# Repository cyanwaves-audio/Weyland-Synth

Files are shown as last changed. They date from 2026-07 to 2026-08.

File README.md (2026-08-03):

# Weyland DOS-1

<p align="center">
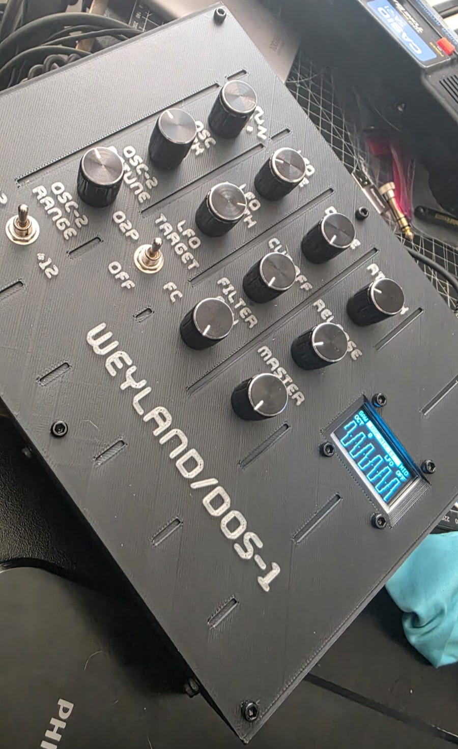
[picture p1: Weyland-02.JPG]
Weyland DOS-1 synthesizer
  
</p>

Weyland DOS-1 is a digital monophonic synthesizer built from scratch around an ESP32-S3.

It features two oscillators, waveform selection, oscillator mix and detune, an AR envelope, a low-pass filter, drive, and an LFO assignable to oscillator 2 pitch or filter cutoff (or off). Audio is generated at 48 kHz and sent through a PCM5102A DAC.

Weyland accepts USB MIDI directly as a device or through an RP2040-based USB host bridge, allowing it to work with class-compliant USB MIDI controllers without a computer.

[Watch it in action here.](https://youtu.be/kIQRiqMi21E)
## Overview

The project includes the synthesizer firmware, USB MIDI host firmware, wiring documentation, component list, and files for the custom 3D-printed enclosure.

Weyland DOS-1 was designed as a complete playable instrument rather than a development board experiment: all user-adjustable synthesis parameters have dedicated physical controls, while the OLED displays the current MIDI source, waveform, oscillator range, LFO assignment, parameter values, and a live scope of the final audio output.

## Features

- Digital monophonic synthesizer running at 48 kHz
- Dual oscillators with shared waveform selection
- Oscillator mix, detune, and octave-range controls
- Low-pass filter with envelope modulation
- Attack–release amplitude envelope
- LFO with adjustable rate and depth
- LFO routing to oscillator 2 pitch, filter cutoff, or off
- Adjustable drive and master output
- Velocity-sensitive MIDI response
- Last-note priority with held-note fallback
- Direct USB MIDI device mode
- USB MIDI host mode through an RP2040 bridge
- OLED status display with live parameter feedback and output waveform scope
- Dedicated physical controls for every synthesis parameter
- PCM5102A I²S audio output
- Custom 3D-printed enclosure

## Architecture

Weyland is built around an ESP32-S3, which runs the synthesis engine, processes the physical controls, receives MIDI, updates the OLED, and sends digital audio to the DAC.

| Component | Function |
| --- | --- |
| ESP32-S3 | Synthesis engine, control processing, MIDI and display |
| RP2040 Pico | USB MIDI host and UART bridge |
| MCP3208 | Eight-channel ADC for the analog controls |
| PCM5102A | 48 kHz I²S digital-to-analog conversion |
| SH1106 OLED | MIDI mode, octave and LFO status display |

MIDI can reach the synthesizer through two paths:

- **Device mode:** A computer or USB host connects directly to the ESP32-S3.
- **Host mode:** A class-compliant USB MIDI controller connects to the RP2040, which forwards the MIDI data to the ESP32-S3 over UART.

## Controls

| Control | Function |
| --- | --- |
| WAVE | Selects the waveform used by both oscillators |
| OSC MIX | Blends oscillator 1 and oscillator 2 |
| OSC-2 DETUNE | Fine-tunes oscillator 2 relative to oscillator 1 |
| OSC -2 RANGE | Shifts oscillator 2 by −12, 0 or +12 semitones |
| LFO RATE | Sets the modulation speed |
| LFO DEPTH | Sets the modulation amount |
| LFO TARGET | Routes the LFO to the filter, oscillator 2 or off |
| DRIVE | Adds saturation to the signal |
| CUTOFF | Sets the low-pass filter cutoff |
| FILTER ENV | Sets the envelope modulation applied to the filter |
| ATTACK | Sets the amplitude-envelope attack time |
| RELEASE | Sets the amplitude-envelope release time |
| MASTER | Sets the output level |

Weyland is monophonic and uses last-note priority. When the current note is released, it returns to the newest note still being held.

## MIDI

Weyland DOS-1 can receive MIDI in two ways:

* **USB device mode:** connect Weyland directly to a computer or DAW.
* **USB host mode:** connect a class-compliant USB MIDI controller through the internal RP2040 Pico bridge.

In host mode, the Pico reads the USB MIDI data and forwards supported messages to the ESP32-S3 using the custom MGP UART protocol. The selected MIDI source is handled exclusively rather than combining both inputs. The display identifies the active source.

### Supported MIDI messages

| MIDI message | Behaviour |
| --- | --- |
| Note On | Plays the received note. Note velocity controls its level. |
| Note Off | Releases the note, subject to sustain-pedal state. |
| Note On with velocity 0 | Treated as Note Off. |
| Pitch Bend | Bends the pitch of the active voice. |
| CC 1 — Modulation Wheel | Adds MIDI-controlled modulation. |
| CC 64 — Sustain Pedal | Defers note releases while the pedal is held. |
| CC 120 — All Sound Off  | Immediately silences the synth. |
| CC 123 — All Notes Off  | Clears the held-note state and releases the voice. |

Weyland listens on all 16 MIDI channels and uses **monophonic last-note priority**. The newest held note becomes active; releasing it returns to the most recently held previous note. The held-note stack also works with sustain-pedal input. The original note-priority and MGP transport behaviour was established in the earlier bridge firmware and retained in the final version.

Channel pressure, polyphonic aftertouch, program changes, MIDI clock, SysEx, and arbitrary MIDI CC control of the front-panel parameters are not currently implemented.

## Hardware

### Core components

| Component | Purpose |
| --- | --- |
| ESP32-S3-WROOM-1 | Main processor and synthesis engine |
| Raspberry Pi Pico / RP2040 | USB MIDI host bridge |
| PCM5102A module | I²S audio output |
| MCP3208 | 12-bit ADC for eight analog controls |
| 1.3-inch SH1106 OLED | Status display |
| Potentiometers and switches | Synth parameter controls |
| Audio output jack | Line-level audio output |
| USB connectors | Power, direct MIDI and USB-host MIDI |
| Custom 3D-printed enclosure | Panel and electronics housing |

## Wiring and Pin Mapping

### ESP32-S3 connections

| GPIO | Connection |
| ---: | --- |
| 1 | MIDI host/device mode selector |
| 4 | Oscillator mix |
| 5 | Oscillator 2 detune |
| 6, 7 | Oscillator 2 octave selector |
| 9, 10 | LFO target selector |
| 11–14 | Waveform selector |
| 15 | UART MIDI input from the RP2040 bridge |
| 16 | OLED SDA |
| 17 | OLED SCL |
| 35 | PCM5102A LRCK |
| 36 | PCM5102A DIN |
| 37 | PCM5102A BCK |
| 39 | MCP3208 CS |
| 40 | MCP3208 MOSI |
| 41 | MCP3208 MISO |
| 42 | MCP3208 SCK |

### MCP3208 channels

| Channel | Control |
| ---: | --- |
| CH0 | LFO rate |
| CH1 | LFO depth |
| CH2 | Drive |
| CH3 | Filter cutoff |
| CH4 | Filter envelope amount |
| CH5 | Attack |
| CH6 | Release |
| CH7 | Master output |

The supplied firmware compensates for the potentiometer orientation used in the original build. If the controls operate backwards in another build, swap the outer potentiometer connections or change the inversion behavior in the firmware.

## Firmware Setup

Weyland uses two separate firmware sketches:

* The **ESP32-S3 firmware** runs the synthesizer, display, controls, direct USB MIDI and MGP receiver.
* The **RP2040 firmware** acts as a USB MIDI host and forwards MIDI to the ESP32-S3.

### Requirements

* Arduino IDE
* **esp32** board package by Espressif Systems
* **Raspberry Pi Pico/RP2040** board package by Earle F. Philhower III
* Adafruit GFX Library
* Adafruit SH110X Library

TinyUSB host support is included with the RP2040 board package.

### ESP32-S3 firmware

The main synthesizer firmware consists of three files:

* `Weyland_v0_28e.ino`
* `WeylandDisplay.cpp`
* `WeylandDisplay.h`

Keep all three files inside the same Arduino sketch folder.

Use these Arduino IDE settings:

| Setting | Value |
| --- | --- |
| Board | ESP32S3 Dev Module |
| USB CDC On Boot | Disabled |
| USB Mode | USB-OTG (TinyUSB)  |

Compile and upload the sketch to the ESP32-S3.

In DEVICE mode, the ESP32-S3 appears as a USB MIDI device named **Weyland DOS-1**.

The OLED uses I²C address `0x3C`. If the display is missing or fails to initialize, the synthesizer will continue operating without it.

### RP2040 USB host firmware

The USB MIDI host bridge uses:

* `Weyland_Pico_USBHost_HardwareReset_v0_5.ino`

Place this file in its own Arduino sketch folder.

Use these Arduino IDE settings:

| Setting | Value |
| --- | --- |
| Board | Raspberry Pi Pico, or the matching RP2040 board |
| USB Stack | Adafruit TinyUSB Host (native) |

Before uploading, place Weyland’s MIDI source switch in **HOST** mode. In DEVICE mode, the hardware reset circuit holds the Pico in reset.

Because the Pico’s USB port runs as a host instead of a serial device, reflashing may require manually entering BOOTSEL mode:

1. Disconnect the Pico from USB.
2. Hold the **BOOTSEL** button.
3. Reconnect USB and release BOOTSEL.
4. Upload the sketch from Arduino IDE.

### ESP32-S3 and Pico connection

The Pico communicates with the ESP32-S3 using the MGP(1) protocol over UART:

| Pico | ESP32-S3 |
| --- | --- |
| GP0 / UART TX | GPIO15 / UART RX through a 1 kΩ resistor |
| GND | GND |

The UART connection runs at `115200` baud.

In HOST mode, the Pico receives MIDI from a class-compliant USB MIDI controller and forwards note, sustain, modulation and pitch-bend messages to the ESP32-S3. In DEVICE mode, the Pico is held in reset and the ESP32-S3 accepts MIDI through its own USB connection.

The Pico firmware uses GP25 for its status LED. Boards with a NeoPixel or a differently wired LED will still operate as MIDI bridges, but their status indicator may not work without changing `LED_PIN`.

(1) MGP: Midi Gremlin Protocol. Weyland’s lightweight custom serial protocol. It packages USB MIDI events into fixed UART messages sent from the RP2040 host bridge to the ESP32-S3.

## MIDI Source Selection

Weyland supports two mutually exclusive MIDI input paths, selected with the physical HOST/DEVICE switch.

| Mode | MIDI source | Behavior |
| --- | --- | --- |
| DEVICE | ESP32-S3 USB port | Weyland appears as a USB MIDI device named **Weyland DOS-1** |
| HOST | RP2040 USB port | A class-compliant USB MIDI controller connects directly to Weyland |

In HOST mode, the RP2040 converts incoming USB MIDI events into MGP messages and forwards them to the ESP32-S3 over UART.

In DEVICE mode, the RP2040 is held in reset by the hardware reset circuit, preventing both MIDI paths from operating simultaneously.

## Enclosure and 3D-Printing Files

The repository includes the files for Weyland’s custom 3D-printed enclosure.

I designed the enclosure in Autodesk Fusion around the specific boards, modules, controls and connectors used in the original build. Components with different dimensions may require modifications to the model.

Before final assembly, test-fit the OLED, potentiometers, switches, USB connectors and audio jack.

### BOM

Exact MCUs I used:

ESP32-S3 N16R8: https://aliexpress.com/item/1005007319706057.html

Raspberry Pi Pico 16MB: https://aliexpress.com/item/1005005617180169.html

I might update the full BOM sometime, but for now this and the provided schematics should be enough to start.

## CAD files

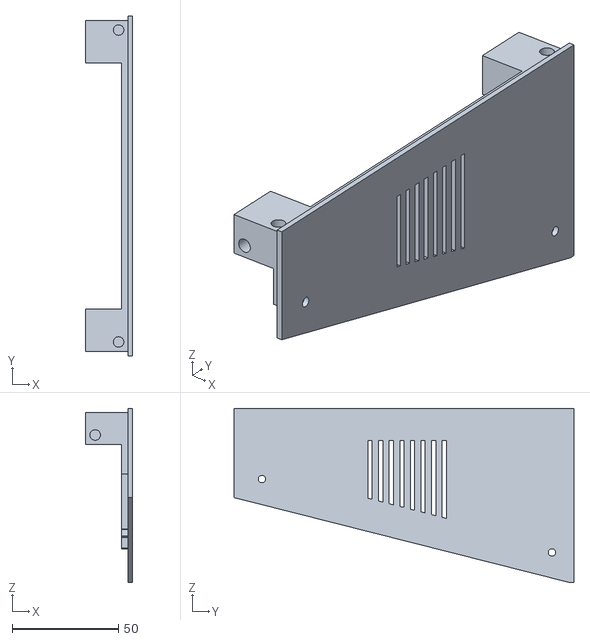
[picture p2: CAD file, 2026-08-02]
3DModels/Weyland_v6_Right.stl
22.0 x 160.0 x 82.0

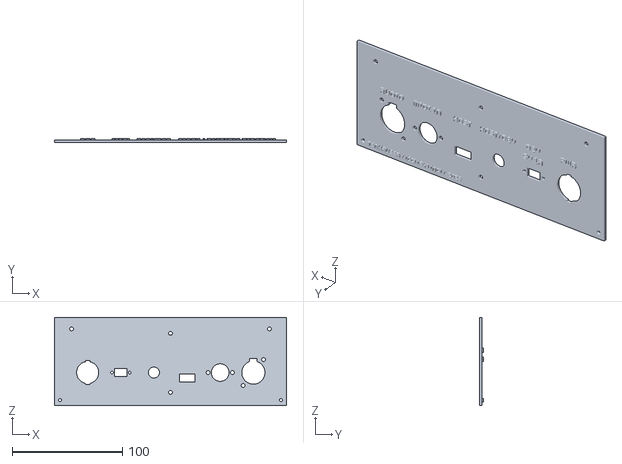
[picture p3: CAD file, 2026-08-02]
3DModels/Weyland_v6_Back.stl
210.0 x 3.50 x 80.0

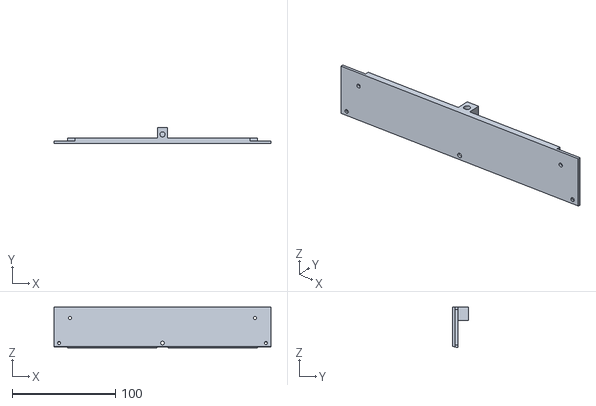
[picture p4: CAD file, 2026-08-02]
3DModels/Weyland_v6_Front.stl
210.0 x 15.0 x 39.3

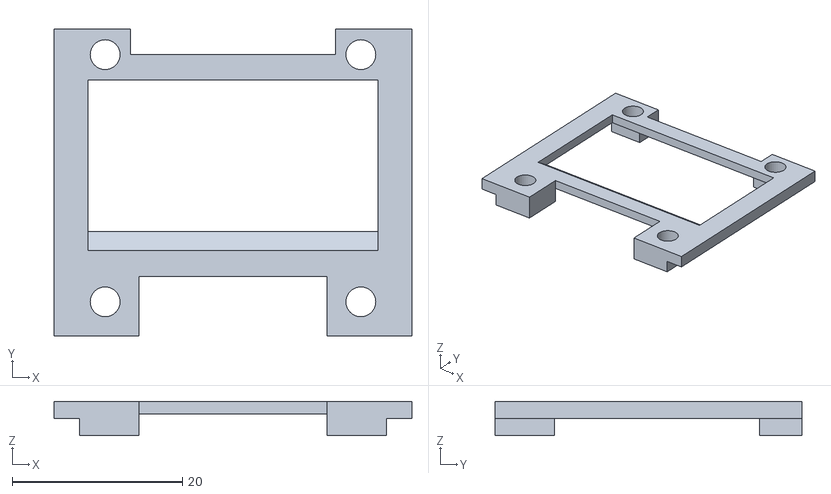
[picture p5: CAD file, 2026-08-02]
3DModels/Weyland_v6_DisplayHolder_rev1.stl
42.0 x 36.0 x 4.00

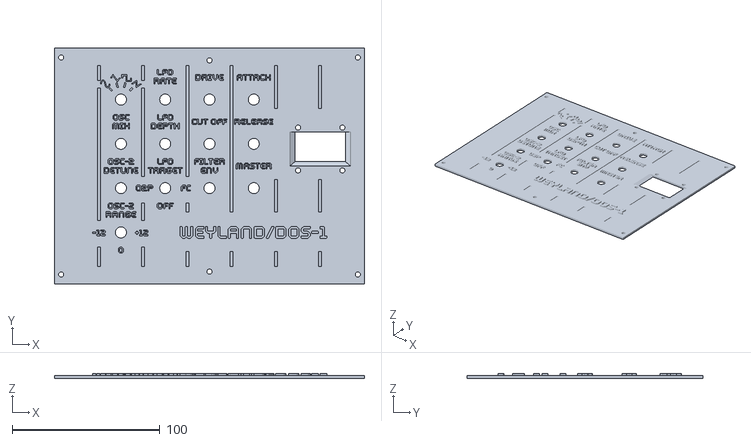
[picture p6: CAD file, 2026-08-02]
3DModels/Weyland_v6_TopPanel_rev1.stl
210.0 x 160.0 x 3.50

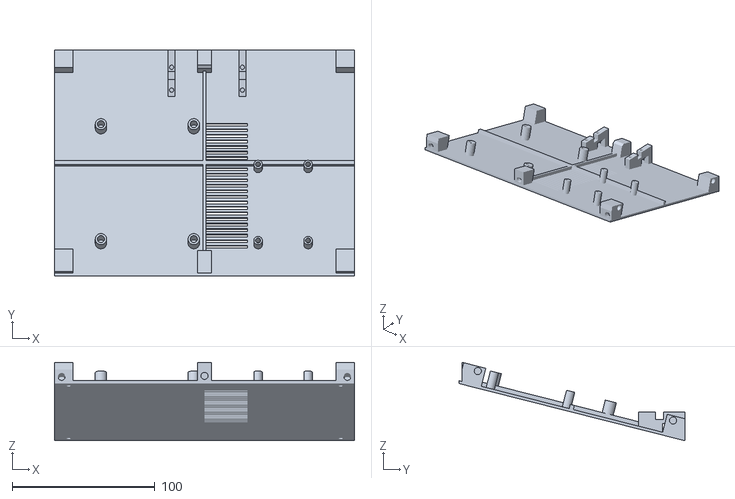
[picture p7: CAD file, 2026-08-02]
3DModels/Weyland_v6_Bottom.stl
210.0 x 158.0 x 54.9

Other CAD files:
3DModels/Weyland_v6_Left.stl

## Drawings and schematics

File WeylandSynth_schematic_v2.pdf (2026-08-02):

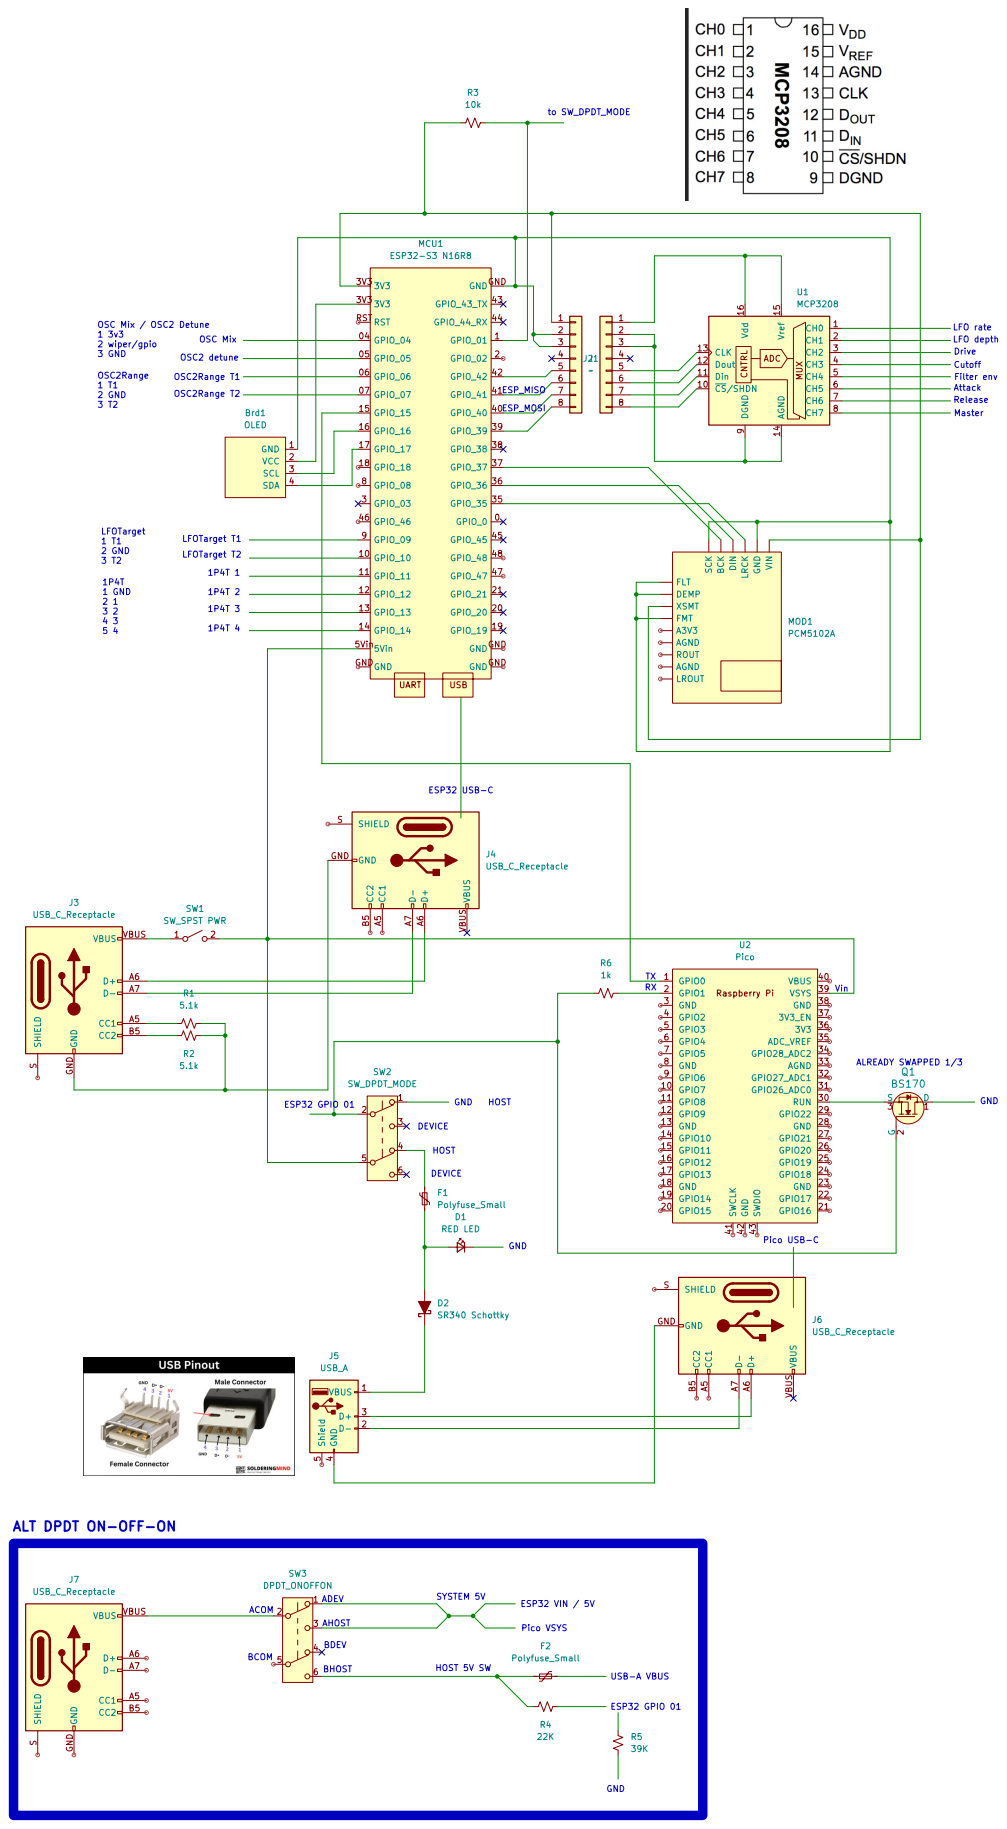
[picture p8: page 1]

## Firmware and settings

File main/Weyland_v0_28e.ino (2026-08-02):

// ============================================================
// Weyland_v0_28e_fixedTimebaseScope
// ESP32-S3 + PCM5102A + MCP3208
//
// Based on Weyland_v0_26_mgpPerformanceControls.
//
// Changes from v0_26:
// - Keeps raw-polled UART1 RX GPIO15; no UART driver / ISR / ringbuffer.
// - Keeps MGP Control Change (0x03) and Pitch Bend (0x04) packets.
// - Makes the physical HOST / DEVICE switch choose exactly one MIDI source.
// - HOST: Pico MGP bridge is accepted; ESP USB MIDI packets are discarded.
// - DEVICE: ESP USB MIDI is accepted; Pico MGP packets are parsed then ignored.
// - Uses GPIO1 INPUT_PULLUP: LOW = HOST, HIGH/open = DEVICE.
// - Debounces mode changes and silences/reset-controls when switching source.
//
// USB CDC On Boot must be Disabled.
// USB Mode: USB-OTG / TinyUSB.
//
// All pots inverted globally because I wired them reversed. Eh.
// Osc2 detune is flipped again because panel direction felt inverted.
// Switches not inverted.
// ============================================================

#include <Arduino.h>
#include <SPI.h>
#include "driver/i2s_std.h"
#include "driver/uart.h"
#include "esp_system.h"
#include "soc/soc.h"
#include "soc/uart_reg.h"
#include <math.h>

#include "USB.h"
#include "USBMIDI.h"
#include "WeylandDisplay.h"

USBMIDI MIDI("Weyland DOS-1");

// -------------------- Types --------------------

enum Waveform {
  WAVE_SINE,
  WAVE_SQUARE,
  WAVE_SAW,
  WAVE_TRIANGLE
};

enum LfoTarget {
  LFO_TARGET_OSC2,
  LFO_TARGET_OFF,
  LFO_TARGET_FILTER
};

// -------------------- Audio --------------------

const int SAMPLE_RATE = 48000;
const int AUDIO_FRAMES = 64;

const int16_t OUTPUT_AMPLITUDE = 24000;
const float SYNTH_HEADROOM_GAIN = 0.55f;

// PCM5102A
const int I2S_WS_PIN   = 35;
const int I2S_DOUT_PIN = 36;
const int I2S_BCK_PIN  = 37;

// -------------------- Direct controls --------------------

const int POT_OSC_MIX_PIN = 4;
const int POT_OSC2_DETUNE_PIN = 5;

const int OSC2_RANGE_LEFT_PIN  = 6;
const int OSC2_RANGE_RIGHT_PIN = 7;

const int LFO_TARGET_LEFT_PIN  = 9;
const int LFO_TARGET_RIGHT_PIN = 10;

const int WAVE_SINE_PIN     = 11;
const int WAVE_TRIANGLE_PIN = 12;
const int WAVE_SQUARE_PIN   = 13;
const int WAVE_SAW_PIN      = 14;

// -------------------- MIDI input source switch --------------------
//
// Wiring on the spare pole of the HOST / DEVICE DPDT switch:
//   Common -> ESP32 GPIO1
//   HOST throw -> GND
//   DEVICE throw -> leave open
//
// INPUT_PULLUP makes an open contact read HIGH.
// Therefore:
//   GPIO1 LOW  = accept Pico USB-host MGP bridge
//   GPIO1 HIGH = accept ESP USB MIDI from the panel USB-C / DAW
const int MIDI_SOURCE_MODE_PIN = 1;
const unsigned long MIDI_SOURCE_DEBOUNCE_MS = 25;

// -------------------- Pico / MGP raw UART bridge --------------------

#define MGP_UART_NUM   UART_NUM_1
#define MGP_RX_PIN     15
#define MGP_BAUD       115200

#define MGP_SYNC_A       0xA5
#define MGP_SYNC_B       0x5A
#define MGP_VER          0x01
#define MGP_MAX_PAYLOAD  16

#define MGP_NOTE_ON         0x01
#define MGP_NOTE_OFF        0x02
#define MGP_CONTROL_CHANGE  0x03
#define MGP_PITCH_BEND      0x04
#define MGP_ALL_NOTES_OFF   0x10
#define MGP_ALL_SOUND_OFF   0x11
#define MGP_ALL_CHANNELS    0xFF

const bool MGP_DEBUG_PRINT = false; //noise cause?
const unsigned long MGP_DEBUG_INTERVAL_MS = 1000;

RTC_DATA_ATTR uint32_t rtcBootCount = 0;

uint32_t mgpRxBytes = 0;
uint32_t mgpPacketsOk = 0;
uint32_t mgpChkFail = 0;
uint32_t mgpBadVer = 0;
uint32_t mgpLenTooBig = 0;
uint32_t mgpSyncLoss = 0;
uint32_t mgpSeqJump = 0;
uint32_t mgpUnknownType = 0;
uint32_t mgpNoteOnCount = 0;
uint32_t mgpNoteOffCount = 0;
uint32_t mgpCcCount = 0;
uint32_t mgpPitchBendCount = 0;
uint32_t mgpAllNotesOffCount = 0;
uint32_t mgpAllSoundOffCount = 0;
uint32_t mgpPacketsIgnoredDeviceMode = 0;
uint32_t mgpMaxFifoSeen = 0;

uint32_t usbPacketsIgnoredHostMode = 0;
uint32_t midiSourceModeSwitchCount = 0;

uint8_t mgpLastSeq = 0;
bool mgpHaveSeq = false;

uint8_t mgpLastType = 0;
uint8_t mgpLastChannel = 0;
uint8_t mgpLastNote = 0;
uint8_t mgpLastVel = 0;

unsigned long lastMgpDebugMs = 0;

// -------------------- MCP3208 --------------------

const int MCP_CS_PIN   = 39;
const int MCP_MOSI_PIN = 40;
const int MCP_MISO_PIN = 41;
const int MCP_SCK_PIN  = 42;

const uint8_t MCP_CH_LFO_RATE   = 0;
const uint8_t MCP_CH_LFO_DEPTH  = 1;
const uint8_t MCP_CH_DRIVE      = 2;
const uint8_t MCP_CH_CUTOFF     = 3;
const uint8_t MCP_CH_FILTER_ENV = 4;
const uint8_t MCP_CH_ATTACK     = 5;
const uint8_t MCP_CH_RELEASE    = 6;
const uint8_t MCP_CH_MASTER     = 7;

SPISettings mcpSpiSettings(1000000, MSBFIRST, SPI_MODE0);

// -------------------- Control timing --------------------

const unsigned long CONTROL_UPDATE_INTERVAL_MS = 10;
unsigned long lastControlUpdateMs = 0;

// -------------------- ADC --------------------

const int ADC_MAX = 4095;
const int ADC_DEADZONE_LOW = 20;
const int ADC_DEADZONE_HIGH = 4075;

const bool INVERT_ALL_POTS = true;
const bool FLIP_OSC2_DETUNE_AFTER_GLOBAL_INVERT = true;

const float OSC_MIX_SMOOTH_AMOUNT = 0.05f;
const float OSC2_DETUNE_SMOOTH_AMOUNT = 0.05f;
const float LFO_DEPTH_SMOOTH_AMOUNT = 0.05f;
const float LFO_RATE_SMOOTH_AMOUNT = 0.05f;
const float DRIVE_SMOOTH_AMOUNT = 0.05f;
const float FILTER_CUTOFF_SMOOTH_AMOUNT = 0.05f;
const float FILTER_ENV_SMOOTH_AMOUNT = 0.05f;
const float ATTACK_SMOOTH_AMOUNT = 0.05f;
const float RELEASE_SMOOTH_AMOUNT = 0.05f;
const float MASTER_SMOOTH_AMOUNT = 0.05f;

// OSC mix and Master directly change audio amplitude/sample balance.
// They are smoothed at the audio rate below so fast knob moves cannot
// create 100 Hz control-step zipper noise.
const float OSC_MIX_AUDIO_SMOOTH_MS = 12.0f;
const float MASTER_AUDIO_SMOOTH_MS = 15.0f;

// -------------------- Synth ranges --------------------

const float MASTER_TUNE_CENTS = 0.0f;

const float OSC2_DETUNE_MIN_CENTS = 0.0f;
const float OSC2_DETUNE_MAX_CENTS = 50.0f;

const float LFO_MAX_DETUNE_DEPTH_CENTS = 40.0f;

// External performance controls.
// CC1 is a separate global vibrato depth; it does not alter panel LFO depth.
// The rate is fixed to keep the wheel predictable regardless of panel LFO settings.
const float MOD_WHEEL_VIBRATO_MAX_CENTS = 50.0f;
const float MOD_WHEEL_VIBRATO_RATE_HZ = 5.0f;

// Standard expressive keyboard default. Change later if a wider bend feels better.
const float PITCH_BEND_RANGE_SEMITONES = 2.0f;

// Extended. Exponential mapping keeps slow end useful.
const float LFO_RATE_MIN_HZ = 0.05f;
const float LFO_RATE_MAX_HZ = 50.0f;

const bool FILTER_ENABLED = true;
const float FILTER_CUTOFF_MIN_HZ = 120.0f;
const float FILTER_CUTOFF_MAX_HZ = 8000.0f;
const float FILTER_ENV_MAX_OCTAVES = 4.0f;
const float FILTER_LFO_MAX_OCTAVES = 3.0f;

// More aggressive than v0_21.
const float DRIVE_MIN_GAIN = 1.0f;
const float DRIVE_MAX_GAIN = 14.0f;
const float DRIVE_HARD_BLEND_MAX = 0.55f;
const float DRIVE_POST_GAIN_MAX = 1.35f;

const float ATTACK_MIN_MS = 1.0f;
const float ATTACK_MAX_MS = 1000.0f;

const float RELEASE_MIN_MS = 20.0f;
const float RELEASE_MAX_MS = 1500.0f;

const float FREQ_SMOOTH_MS = 5.0f;
const float VELOCITY_SMOOTH_MS = 5.0f;
const float ENVELOPE_SILENCE_THRESHOLD = 0.001f;

const uint8_t MIDI_LISTEN_CHANNEL = 255;
const int MAX_HELD_NOTES = 16;

enum MidiSourceMode {
  MIDI_SOURCE_DEVICE,
  MIDI_SOURCE_HOST
};

MidiSourceMode midiSourceMode = MIDI_SOURCE_DEVICE;
MidiSourceMode midiSourceCandidate = MIDI_SOURCE_DEVICE;
unsigned long midiSourceCandidateSinceMs = 0;

// -------------------- State --------------------

struct ControlState {
  float oscMixRaw;
  float oscMixSmoothed;

  float osc2DetuneRaw;
  float osc2DetuneSmoothed;
  float osc2DetuneCents;

  int osc2RangeSemitones;

  float lfoDepthRaw;
  float lfoDepthSmoothed;
  float lfoDepthCents;

  float lfoRateRaw;
  float lfoRateSmoothed;
  float lfoRateHz;

  LfoTarget lfoTarget;

  float driveRaw;
  float driveSmoothed;

  float filterCutoffRaw;
  float filterCutoffSmoothed;
  float filterCutoffHz;

  float filterEnvRaw;
  float filterEnvSmoothed;
  float filterEnvAmount;

  float attackRaw;
  float attackSmoothed;
  float attackMs;

  float releaseRaw;
  float releaseSmoothed;
  float releaseMs;

  float masterRaw;
  float masterSmoothed;
};

struct NoteState {
  bool gate;
  float targetFreqHz;
  float currentFreqHz;
  float finalFreqHz;
  int activeMidiNote;
  int velocity;
  float targetVelocityGain;
  float currentVelocityGain;
};

struct HeldNote {
  uint8_t note;
  uint8_t velocity;
  bool keyDown;
};

enum EnvelopeStage {
  ENV_IDLE,
  ENV_ATTACK,
  ENV_SUSTAIN,
  ENV_RELEASE
};

struct EnvelopeState {
  EnvelopeStage stage;
  float level;
  float attackStep;
  float releaseStep;
};

ControlState controlState = {
  0.5f, 0.5f,

  0.15f, 0.15f, 7.0f,

  0,

  0.0f, 0.0f, 0.0f,

  0.0f, 0.0f, LFO_RATE_MIN_HZ,

  LFO_TARGET_OFF,

  0.0f, 0.0f,

  1.0f, 1.0f, FILTER_CUTOFF_MAX_HZ,

  0.0f, 0.0f, 0.0f,

  0.0f, 0.0f, ATTACK_MIN_MS,

  0.1f, 0.1f, 150.0f,

  0.0f, 0.0f
};

NoteState noteState = {
  false,
  146.83f, 146.83f, 146.83f,
  -1, 0,
  0.0f, 0.0f
};

EnvelopeState envelope = {
  ENV_IDLE,
  0.0f,
  0.0f,
  0.0f
};

Waveform currentWaveform = WAVE_SAW;

HeldNote heldNotes[MAX_HELD_NOTES];
int heldNoteCount = 0;

float osc1Phase = 0.0f;
float osc2Phase = 0.0f;
float osc1PhaseInc = 0.0f;
float osc2PhaseInc = 0.0f;

float lfoPhase = 0.0f;
float lfoPhaseInc = 0.0f;
float currentLfoValue = 0.0f;

// Independent mod-wheel vibrato state.
float modVibratoPhase = 0.0f;
float currentModVibratoCents = 0.0f;
float modWheelVibratoDepthCents = 0.0f;

// Full 14-bit pitch bend, expressed as cents for cheap per-sample use.
float pitchBendCents = 0.0f;

// CC64 state.
bool sustainPedalDown = false;

float currentOsc2DetuneCents = 7.0f;
float currentOsc2Ratio = 1.0f;
float cachedOsc2TotalCents = 999999.0f;

float filterState = 0.0f;
float filterAlpha = 1.0f;

float freqSmoothAlpha = 1.0f;
float velocitySmoothAlpha = 1.0f;

// Audio-rate smoothing states for controls that otherwise cause audible
// zippering when the 10 ms panel scanner updates quickly.
float oscMixAudioSmoothed = 0.5f;
float masterAudioSmoothed = 0.0f;
float oscMixAudioSmoothAlpha = 1.0f;
float masterAudioSmoothAlpha = 1.0f;
float masterTuneRatio = 1.0f;

i2s_chan_handle_t tx_handle = nullptr;
int16_t audioBuffer[AUDIO_FRAMES * 2];

// -------------------- Forward declarations --------------------

void handleMidiNoteOff(uint8_t noteNumber);
void handleMidiControlChange(uint8_t controller, uint8_t value);
void handleMidiPitchBend(uint8_t lsb, uint8_t msb);
void updateEnvelopeSteps();
void allSoundOffImmediate();

// -------------------- Utility --------------------

float clamp01(float x) {
  if (x < 0.0f) return 0.0f;
  if (x > 1.0f) return 1.0f;
  return x;
}

float clampFloat(float x, float low, float high) {
  if (x < low) return low;
  if (x > high) return high;
  return x;
}

float mapFloat(float x, float inMin, float inMax, float outMin, float outMax) {
  return outMin + ((x - inMin) * (outMax - outMin) / (inMax - inMin));
}

float mapExp(float x, float outMin, float outMax) {
  x = clamp01(x);
  return outMin * powf(outMax / outMin, x);
}

float centsToRatio(float cents) {
  return powf(2.0f, cents / 1200.0f);
}

float midiNoteToFrequency(uint8_t noteNumber) {
  return 440.0f * powf(2.0f, ((float)noteNumber - 69.0f) / 12.0f);
}

float smoothingAlphaFromMs(float ms) {
  if (ms <= 0.0f) return 1.0f;
  return 1.0f - expf(-1.0f / ((ms / 1000.0f) * (float)SAMPLE_RATE));
}

int applyAdcDeadzones(int adc) {
  if (adc < ADC_DEADZONE_LOW) return 0;
  if (adc > ADC_DEADZONE_HIGH) return ADC_MAX;
  return adc;
}

float normalizePotAdc(int adc) {
  adc = applyAdcDeadzones(adc);

  float value = clamp01((float)adc / (float)ADC_MAX);

  if (INVERT_ALL_POTS) {
    value = 1.0f - value;
  }

  return clamp01(value);
}

// -------------------- MCP3208 hardware SPI --------------------

uint16_t readMcp3208Channel(uint8_t channel) {
  if (channel > 7) return 0;

  uint8_t command1 = 0b00000110 | ((channel & 0b100) >> 2);
  uint8_t command2 = (channel & 0b011) << 6;

  SPI.beginTransaction(mcpSpiSettings);
  digitalWrite(MCP_CS_PIN, LOW);

  SPI.transfer(command1);
  uint8_t highByte = SPI.transfer(command2);
  uint8_t lowByte = SPI.transfer(0x00);

  digitalWrite(MCP_CS_PIN, HIGH);
  SPI.endTransaction();

  return (((uint16_t)(highByte & 0x0F) << 8) | lowByte) & 0x0FFF;
}

float readDirectPotNormalized(int pin) {
  return normalizePotAdc(analogRead(pin));
}

float readMcpPotNormalized(uint8_t channel) {
  return normalizePotAdc((int)readMcp3208Channel(channel));
}

// -------------------- Switches --------------------

int readOsc2RangeSemitones() {
  bool left  = digitalRead(OSC2_RANGE_LEFT_PIN) == LOW;
  bool right = digitalRead(OSC2_RANGE_RIGHT_PIN) == LOW;

  if (left && !right) return -12;
  if (!left && !right) return 0;
  if (!left && right) return 12;

  return 0;
}

LfoTarget readLfoTarget() {
  bool left  = digitalRead(LFO_TARGET_LEFT_PIN) == LOW;
  bool right = digitalRead(LFO_TARGET_RIGHT_PIN) == LOW;

  if (left && !right) return LFO_TARGET_FILTER;
  if (!left && !right) return LFO_TARGET_OFF;
  if (!left && right) return LFO_TARGET_OSC2;

  return LFO_TARGET_OFF;
}

void updateWaveSelector() {
  bool sine     = digitalRead(WAVE_SINE_PIN) == LOW;
  bool triangle = digitalRead(WAVE_TRIANGLE_PIN) == LOW;
  bool square   = digitalRead(WAVE_SQUARE_PIN) == LOW;
  bool saw      = digitalRead(WAVE_SAW_PIN) == LOW;

  int activeCount = 0;
  if (sine) activeCount++;
  if (triangle) activeCount++;
  if (square) activeCount++;
  if (saw) activeCount++;

  if (activeCount != 1) {
    return;
  }

  if (sine) {
    currentWaveform = WAVE_SINE;
  } else if (triangle) {
    currentWaveform = WAVE_TRIANGLE;
  } else if (square) {
    currentWaveform = WAVE_SQUARE;
  } else if (saw) {
    currentWaveform = WAVE_SAW;
  }
}

// -------------------- Waveforms --------------------

static inline float renderWave(float phase) {
  switch (currentWaveform) {
    case WAVE_SINE:
      return sinf(2.0f * PI * phase);

    case WAVE_SQUARE:
      return (phase < 0.5f) ? 1.0f : -1.0f;

    case WAVE_SAW:
      return (2.0f * phase) - 1.0f;

    case WAVE_TRIANGLE:
      if (phase < 0.25f) return phase * 4.0f;
      if (phase < 0.75f) return 2.0f - (phase * 4.0f);
      return (phase * 4.0f) - 4.0f;

    default:
      return 0.0f;
  }
}

float waveformGain(Waveform wave) {
  switch (wave) {
    case WAVE_SINE:
      return 1.5f;

    case WAVE_TRIANGLE:
      return 1.75f;

    case WAVE_SAW:
      return 0.35f;

    case WAVE_SQUARE:
      return 0.35f;

    default:
      return 1.0f;
  }
}

// -------------------- Controls --------------------

void setupControls() {
  pinMode(POT_OSC_MIX_PIN, INPUT);
  pinMode(POT_OSC2_DETUNE_PIN, INPUT);

  analogReadResolution(12);
  analogSetPinAttenuation(POT_OSC_MIX_PIN, ADC_11db);
  analogSetPinAttenuation(POT_OSC2_DETUNE_PIN, ADC_11db);

  pinMode(OSC2_RANGE_LEFT_PIN, INPUT_PULLUP);
  pinMode(OSC2_RANGE_RIGHT_PIN, INPUT_PULLUP);

  pinMode(LFO_TARGET_LEFT_PIN, INPUT_PULLUP);
  pinMode(LFO_TARGET_RIGHT_PIN, INPUT_PULLUP);

  pinMode(WAVE_SINE_PIN, INPUT_PULLUP);
  pinMode(WAVE_TRIANGLE_PIN, INPUT_PULLUP);
  pinMode(WAVE_SQUARE_PIN, INPUT_PULLUP);
  pinMode(WAVE_SAW_PIN, INPUT_PULLUP);

  pinMode(MCP_CS_PIN, OUTPUT);
  digitalWrite(MCP_CS_PIN, HIGH);

  SPI.begin(MCP_SCK_PIN, MCP_MISO_PIN, MCP_MOSI_PIN, MCP_CS_PIN);
}

void readControlInputs() {
  controlState.oscMixRaw = readDirectPotNormalized(POT_OSC_MIX_PIN);

  controlState.osc2DetuneRaw = readDirectPotNormalized(POT_OSC2_DETUNE_PIN);
  if (FLIP_OSC2_DETUNE_AFTER_GLOBAL_INVERT) {
    controlState.osc2DetuneRaw = 1.0f - controlState.osc2DetuneRaw;
  }

  controlState.lfoRateRaw = readMcpPotNormalized(MCP_CH_LFO_RATE);
  controlState.lfoDepthRaw = readMcpPotNormalized(MCP_CH_LFO_DEPTH);
  controlState.driveRaw = readMcpPotNormalized(MCP_CH_DRIVE);
  controlState.filterCutoffRaw = readMcpPotNormalized(MCP_CH_CUTOFF);
  controlState.filterEnvRaw = readMcpPotNormalized(MCP_CH_FILTER_ENV);
  controlState.attackRaw = readMcpPotNormalized(MCP_CH_ATTACK);
  controlState.releaseRaw = readMcpPotNormalized(MCP_CH_RELEASE);
  controlState.masterRaw = readMcpPotNormalized(MCP_CH_MASTER);

  controlState.osc2RangeSemitones = readOsc2RangeSemitones();
  controlState.lfoTarget = readLfoTarget();

  updateWaveSelector();
}

void smoothControls(bool immediate) {
  if (immediate) {
    controlState.oscMixSmoothed = controlState.oscMixRaw;
    controlState.osc2DetuneSmoothed = controlState.osc2DetuneRaw;
    controlState.lfoDepthSmoothed = controlState.lfoDepthRaw;
    controlState.lfoRateSmoothed = controlState.lfoRateRaw;
    controlState.driveSmoothed = controlState.driveRaw;
    controlState.filterCutoffSmoothed = controlState.filterCutoffRaw;
    controlState.filterEnvSmoothed = controlState.filterEnvRaw;
    controlState.attackSmoothed = controlState.attackRaw;
    controlState.releaseSmoothed = controlState.releaseRaw;
    controlState.masterSmoothed = controlState.masterRaw;
    return;
  }

  controlState.oscMixSmoothed +=
    (controlState.oscMixRaw - controlState.oscMixSmoothed) * OSC_MIX_SMOOTH_AMOUNT;

  controlState.osc2DetuneSmoothed +=
    (controlState.osc2DetuneRaw - controlState.osc2DetuneSmoothed) * OSC2_DETUNE_SMOOTH_AMOUNT;

  controlState.lfoDepthSmoothed +=
    (controlState.lfoDepthRaw - controlState.lfoDepthSmoothed) * LFO_DEPTH_SMOOTH_AMOUNT;

  controlState.lfoRateSmoothed +=
    (controlState.lfoRateRaw - controlState.lfoRateSmoothed) * LFO_RATE_SMOOTH_AMOUNT;

  controlState.driveSmoothed +=
    (controlState.driveRaw - controlState.driveSmoothed) * DRIVE_SMOOTH_AMOUNT;

  controlState.filterCutoffSmoothed +=
    (controlState.filterCutoffRaw - controlState.filterCutoffSmoothed) * FILTER_CUTOFF_SMOOTH_AMOUNT;

  controlState.filterEnvSmoothed +=
    (controlState.filterEnvRaw - controlState.filterEnvSmoothed) * FILTER_ENV_SMOOTH_AMOUNT;

  controlState.attackSmoothed +=
    (controlState.attackRaw - controlState.attackSmoothed) * ATTACK_SMOOTH_AMOUNT;

  controlState.releaseSmoothed +=
    (controlState.releaseRaw - controlState.releaseSmoothed) * RELEASE_SMOOTH_AMOUNT;

  controlState.masterSmoothed +=
    (controlState.masterRaw - controlState.masterSmoothed) * MASTER_SMOOTH_AMOUNT;
}

void deriveControlValues() {
  controlState.osc2DetuneCents =
    mapFloat(
      controlState.osc2DetuneSmoothed,
      0.0f,
      1.0f,
      OSC2_DETUNE_MIN_CENTS,
      OSC2_DETUNE_MAX_CENTS
    );

  controlState.lfoDepthCents =
    controlState.lfoDepthSmoothed * LFO_MAX_DETUNE_DEPTH_CENTS;

  controlState.lfoRateHz =
    mapExp(
      controlState.lfoRateSmoothed,
      LFO_RATE_MIN_HZ,
      LFO_RATE_MAX_HZ
    );

  // Exponential frequency mapping keeps the useful low/mid filter range
  // spread across more of the pot travel.
  controlState.filterCutoffHz =
    mapExp(
      controlState.filterCutoffSmoothed,
      FILTER_CUTOFF_MIN_HZ,
      FILTER_CUTOFF_MAX_HZ
    );

  controlState.filterEnvAmount = clamp01(controlState.filterEnvSmoothed);

  controlState.attackMs =
    mapFloat(
      controlState.attackSmoothed,
      0.0f,
      1.0f,
      ATTACK_MIN_MS,
      ATTACK_MAX_MS
    );

  controlState.releaseMs =
    mapFloat(
      controlState.releaseSmoothed,
      0.0f,
      1.0f,
      RELEASE_MIN_MS,
      RELEASE_MAX_MS
    );

  updateEnvelopeSteps();
}

void updateControls() {
  readControlInputs();
  smoothControls(false);
  deriveControlValues();
}

void initializeControlState() {
  // Let ADC/SPI/control rails settle.
  delay(30);

  // Throw away early reads. MCP/ADC startup can be a little goblin.
  for (int i = 0; i < 6; i++) {
    readControlInputs();
    delay(3);
  }

  smoothControls(true);
  deriveControlValues();

  // Explicitly force envelope timing from startup pot state.
  updateEnvelopeSteps();
}

bool updateControlsIfDue() {
  unsigned long now = millis();

  if (now - lastControlUpdateMs < CONTROL_UPDATE_INTERVAL_MS) {
    return false;
  }

  lastControlUpdateMs = now;
  updateControls();
  return true;
}

// -------------------- OLED status bridge --------------------
//
// Runs only after a slow control update. It only copies panel/state data
// into the display module; it never performs I2C work in the audio loop.
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
void loop() {
  // Poll first so a source hand-off takes effect before either input is used.
  updateMidiSourceModeGate();

  // MGP is always drained. handleMgpPacket() applies it only in HOST mode.
  pollMgpRawUart();

  // USB is always drained. handleMidiPacket() applies it only in DEVICE mode.
  updateMidiInput();

  pollMgpRawUart();

  if (updateControlsIfDue()) {
    updateDisplayStatusFromControls();
  }

  pollMgpRawUart();

  fillAudioBuffer();

  pollMgpRawUart();

  size_t bytesWritten = 0;

  i2s_channel_write(
    tx_handle,
    audioBuffer,
    sizeof(audioBuffer),
    &bytesWritten,
    portMAX_DELAY
  );

  pollMgpRawUart();

  printMgpDebugIfDue();
}

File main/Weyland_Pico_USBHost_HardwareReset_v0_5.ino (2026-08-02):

#include "Adafruit_TinyUSB.h"
#include "hardware/watchdog.h"

#ifndef USE_TINYUSB_HOST
  #error "Set Tools -> USB Stack -> Adafruit TinyUSB Host (Native)"
#endif

// ============================================================
// Weyland_Pico_USBHost_HardwareReset_v0_5
//
// USB MIDI host -> Weyland MGP bridge.
//
// Target ESP firmware:
//   Weyland_v0_27_modeGate
//   MGP_DEBUG_PRINT = false
//
// Hardware:
//   Pico GP0 -> 1k -> ESP GPIO15 RX
//   Pico GND -------- ESP GND
//
// Mode/reset wiring:
//   Existing mode node:
//     DPDT common <-> ESP GPIO1 <-> 10k pull-up to ESP 3V3
//
//   That node drives a BS170 reset clamp:
//     BS170 gate   -> mode node
//     BS170 source -> common GND
//     BS170 drain  -> Pico RUN
//
// Result:
//   HOST   = mode node LOW  -> BS170 OFF -> Pico RUN released
//   DEVICE = mode node HIGH -> BS170 ON  -> Pico RUN held LOW
//
// The Pico has no mode-sense input now.
// GP1 is unused and may be physically disconnected.
//
// Startup behavior:
//   The Pico can only run in HOST mode, because it is held in reset
//   while DEVICE mode is selected. On every HOST entry, it boots from
//   a clean state, waits for USB-A VBUS/controller power-up, then
//   starts TinyUSB host.
//
// Physical USB unplug/replug in HOST:
//   A normal remount is allowed first. If none occurs after 800 ms,
//   Pico reboots and starts the host stack fresh.
//
// LED:
//   Fast blink   = boot/startup wait
//   Slow blink   = HOST running, no USB device
//   Double blink = USB device mounted, but no MIDI interface
//   Solid        = USB MIDI interface mounted
//   Brief off    = incoming MIDI activity
// ============================================================

// -------------------- Hardware --------------------

constexpr uint8_t UART_TX_PIN = 0;  // GP0 -> ESP GPIO15 through 1k
constexpr uint8_t LED_PIN     = 25;
constexpr uint32_t UART_BAUD  = 115200;

// -------------------- Timing --------------------

constexpr uint32_t HOST_BOOT_SETTLE_MS     = 1200;
constexpr uint32_t HOST_BEGIN_RETRY_MS     = 600;
constexpr uint32_t UNMOUNT_REBOOT_DELAY_MS = 800;

// -------------------- USB host --------------------

Adafruit_USBH_Host USBHost;

bool hostStackStarted = false;
bool hostStartPending = false;
uint32_t hostStartAtMs = 0;

bool unplugRebootPending = false;
uint32_t unplugRebootAtMs = 0;

volatile bool anyUsbMounted = false;
volatile bool midiMounted = false;
volatile uint32_t lastMidiActivityMs = 0;

// -------------------- LED state --------------------

uint32_t lastLedMs = 0;
uint8_t blinkStep = 0;
bool ledState = false;

// -------------------- MGP v1 --------------------
// Frame: A5 5A VER SEQ TYPE LEN PAYLOAD... XOR
// XOR: VER ^ SEQ ^ TYPE ^ LEN ^ payload bytes

constexpr uint8_t MGP_SYNC_1  = 0xA5;
constexpr uint8_t MGP_SYNC_2  = 0x5A;
constexpr uint8_t MGP_VERSION = 0x01;

constexpr uint8_t MGP_NOTE_ON        = 0x01;
constexpr uint8_t MGP_NOTE_OFF       = 0x02;
constexpr uint8_t MGP_CONTROL_CHANGE = 0x03;
constexpr uint8_t MGP_PITCH_BEND     = 0x04;
constexpr uint8_t MGP_ALL_SOUND_OFF  = 0x11;

constexpr uint8_t MIDI_CC_MOD_WHEEL = 1;
constexpr uint8_t MIDI_CC_SUSTAIN   = 64;
constexpr uint8_t MGP_ALL_CHANNELS  = 0xFF;

uint8_t mgpSequence = 0;

// -------------------- MIDI parser state --------------------

uint8_t runningStatus = 0;
uint8_t messageData[2] = {0, 0};
uint8_t dataCount = 0;
uint8_t dataNeeded = 0;

// -------------------- Forward declarations --------------------

void requestPicoReboot();
void clearUsbState();
void resetMidiParser();
void scheduleHostStart(uint32_t delayMs);
void serviceHostStart();
void serviceUnplugRecovery();
void updateLed();

void sendMgpAllSoundOff();
void sendMgpNoteOn(uint8_t channel, uint8_t note, uint8_t velocity);
void sendMgpNoteOff(uint8_t channel, uint8_t note, uint8_t releaseVelocity);
void sendMgpControlChange(uint8_t channel, uint8_t controller, uint8_t value);
void sendMgpPitchBend(uint8_t channel, uint8_t lsb, uint8_t msb);

// -------------------- Host / reboot control --------------------

void requestPicoReboot() {
  // Do not wait for Serial1.flush() here. During a USB-host fault,
  // reset must remain the smallest, most deterministic recovery path.
  //
  // The 5 ms watchdog delay allows the final all-sound-off packet
  // a brief chance to leave UART FIFO before normal RP2040 reboot.
  watchdog_reboot(0, 0, 5);

  // No more USB/MIDI work after reboot has been requested.
  while (true) {
  }
}

void clearUsbState() {
  anyUsbMounted = false;
  midiMounted = false;
  lastMidiActivityMs = 0;
}

void resetMidiParser() {
  runningStatus = 0;
  messageData[0] = 0;
  messageData[1] = 0;
  dataCount = 0;
  dataNeeded = 0;
}

void scheduleHostStart(uint32_t delayMs) {
  hostStartPending = true;
  hostStartAtMs = millis() + delayMs;
}

void serviceHostStart() {
  if (!hostStartPending || hostStackStarted) {
    return;
  }

  if (static_cast<int32_t>(millis() - hostStartAtMs) < 0) {
    return;
  }

  hostStartPending = false;
  clearUsbState();
  resetMidiParser();

  if (USBHost.begin(0)) {
    hostStackStarted = true;
  } else {
    // Leave the Pico alive and retry after the host hardware settles.
    scheduleHostStart(HOST_BEGIN_RETRY_MS);
  }
}

void serviceUnplugRecovery() {
  if (!unplugRebootPending) {
    return;
  }

  if (midiMounted) {
    unplugRebootPending = false;
    return;
  }

  if (static_cast<int32_t>(millis() - unplugRebootAtMs) < 0) {
    return;
  }

  // No normal remount arrived after a physical unplug.
  sendMgpAllSoundOff();
  requestPicoReboot();
}

// -------------------- MGP sender --------------------

uint8_t mgpChecksum(
  uint8_t version,
  uint8_t sequence,
  uint8_t type,
  uint8_t length,
  const uint8_t* payload
) {
  uint8_t checksum = version ^ sequence ^ type ^ length;

  for (uint8_t i = 0; i < length; ++i) {
    checksum ^= payload[i];
  }

  return checksum;
}

void sendMgpPacket(uint8_t type, const uint8_t* payload, uint8_t length) {
  const uint8_t checksum =
    mgpChecksum(MGP_VERSION, mgpSequence, type, length, payload);

  Serial1.write(MGP_SYNC_1);
  Serial1.write(MGP_SYNC_2);
  Serial1.write(MGP_VERSION);
  Serial1.write(mgpSequence);
  Serial1.write(type);
  Serial1.write(length);

  for (uint8_t i = 0; i < length; ++i) {
    Serial1.write(payload[i]);
  }

  Serial1.write(checksum);
  ++mgpSequence;
}

void sendMgpNoteOn(uint8_t channel, uint8_t note, uint8_t velocity) {
  const uint8_t payload[3] = {
    static_cast<uint8_t>(channel & 0x0F),
    static_cast<uint8_t>(note & 0x7F),
    static_cast<uint8_t>(velocity & 0x7F)
  };

  sendMgpPacket(MGP_NOTE_ON, payload, sizeof(payload));
}

void sendMgpNoteOff(uint8_t channel, uint8_t note, uint8_t releaseVelocity) {
  const uint8_t payload[3] = {
    static_cast<uint8_t>(channel & 0x0F),
    static_cast<uint8_t>(note & 0x7F),
    static_cast<uint8_t>(releaseVelocity & 0x7F)
  };

  sendMgpPacket(MGP_NOTE_OFF, payload, sizeof(payload));
}
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
